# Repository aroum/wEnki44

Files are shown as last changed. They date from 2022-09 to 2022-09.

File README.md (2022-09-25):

# wEnki44

wEnki44 is a wireless version of Enki42 with a useless appendix.

Gerber files and STL models can be downloaded in [releases](https://github.com/aroum/wEnki44/releases).

## Typing

youtube video (click pic) by [@krikun98](https://github.com/krikun98)

Watch the video (https://youtu.be/zcw8uevsyJg)

## wEnki42

**Q:** Why is the pcb logo "wEnki42" even though the keyboard is called "wEnki44"?

**A:** This is a call to break off the useless appendix and use the [Watchman’s Layouts ](https://github.com/aroum/Watchman-layouts).

## Inspiration

* [nrfMicro](https://github.com/joric/nrfmicro)
* [Jian](https://github.com/KGOH/Jian-Info)
* [enki42](https://www.reddit.com/r/ErgoMechKeyboards/comments/qeq2qg/enki42_slim_ergo_keyboard/)
  
## Features

* 44/42 keys
* Kailh Choc V1 switches
* Choc spacing
* Direct pins 
* Wireless
* Full body Tenting case with magnets
* Power switch and reset button
* NFC tag

# Firmware

[wEnki44 zmk config](https://github.com/krikun98/zmk-config/tree/wEnki44) by [@krikun98](https://github.com/krikun98)

You can use firmware from [Jorian840](https://github.com/krikun98/jorian840), they are fully compatible. 

# BOM

| Item | Quantity | Remarks |
| --- | ---: | --- |
| [Kailh Choc V1](https://aliexpress.ru/item/32959996455.html) | 44/42 | switches |
| [Keycaps](https://aliexpress.ru/item/33026798318.html) | 44/42 | 1U (choc spacing) |
| [SMD button 3x4x2mm](https://aliexpress.ru/item/1005003812819985.html) | 2 | for reset |
| [MSK-12C02](https://aliexpress.ru/item/1005001398386692.html) | 2 | Power switch |
| [702035](https://aliexpress.ru/item/1005003738158239.html) | 2 | Or any battery size up to 21x47x8.8mm|
| [Magnets](https://aliexpress.ru/item/1005002757445161.html) | 50-70 | disc 7x2 mm |
| [Bumpers](https://aliexpress.ru/item/4001188580018.html) | 28 | 5x2 mm |
| [NFC-tag Ntag213](https://aliexpress.ru/item/1005001731694350.html) | 1-2 | for top case |

[Holyiot 18010](https://aliexpress.ru/item/32951888809.html) is used as a BLE module. 

All everything else is the same to [nrfMicro](https://github.com/joric/nrfmicro/wiki/Components)

Interactive BOM is located ```/pcb/ibom```

# NFC

You can program an NFC tag to connect to a keyboard or open a KLE using the [NFC Tools](https://play.google.com/store/apps/details?id=com.wakdev.wdnfc) app

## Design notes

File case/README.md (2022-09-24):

# CASE
 
For left-handed version you need to mirror the model.

The pcb is fixed by friction and screws. Use scale factor or sandpaper to fit details

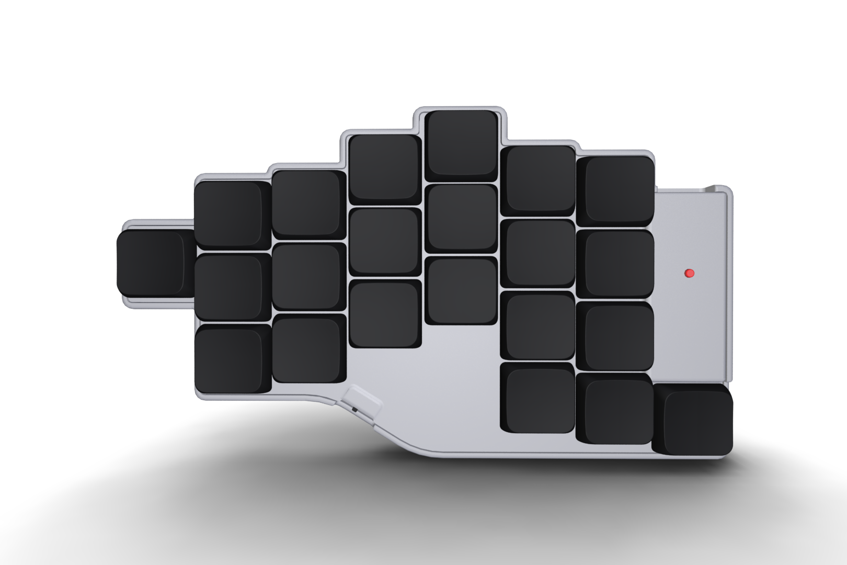
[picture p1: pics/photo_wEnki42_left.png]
wEnki42_left

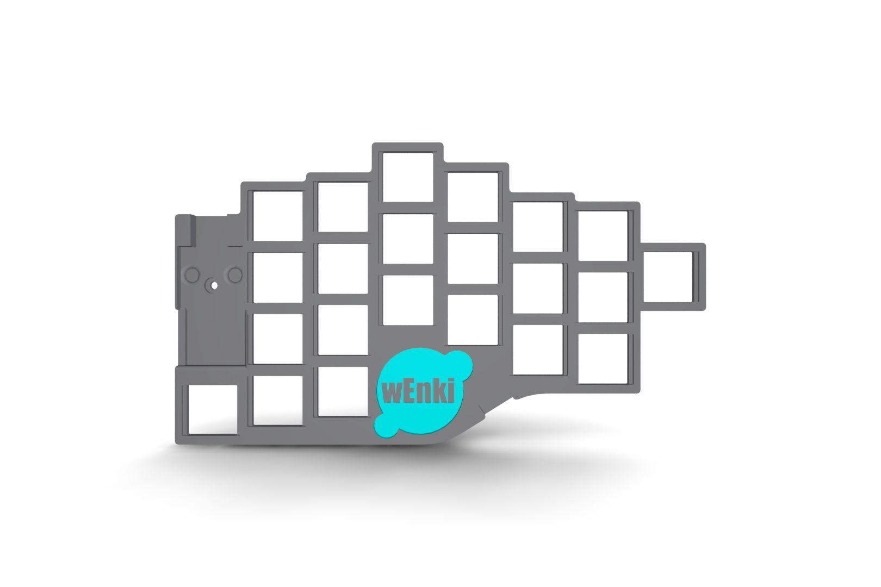
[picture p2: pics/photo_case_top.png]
case_top

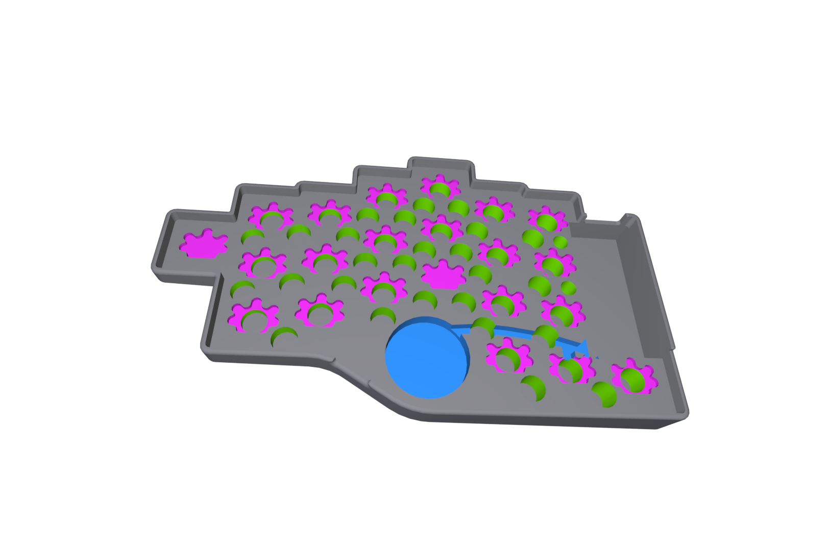
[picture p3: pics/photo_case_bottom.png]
case_bottom


# Print options: 
* Printer: Voxelab proxima
* Rafts: No
* Supports: Yes
* Resolution: 0.05mm
* Resin material: ABS-like

# STL
STL models for 44 & 42 variants can be downloaded in [releases](https://github.com/aroum/kalmar/releases).

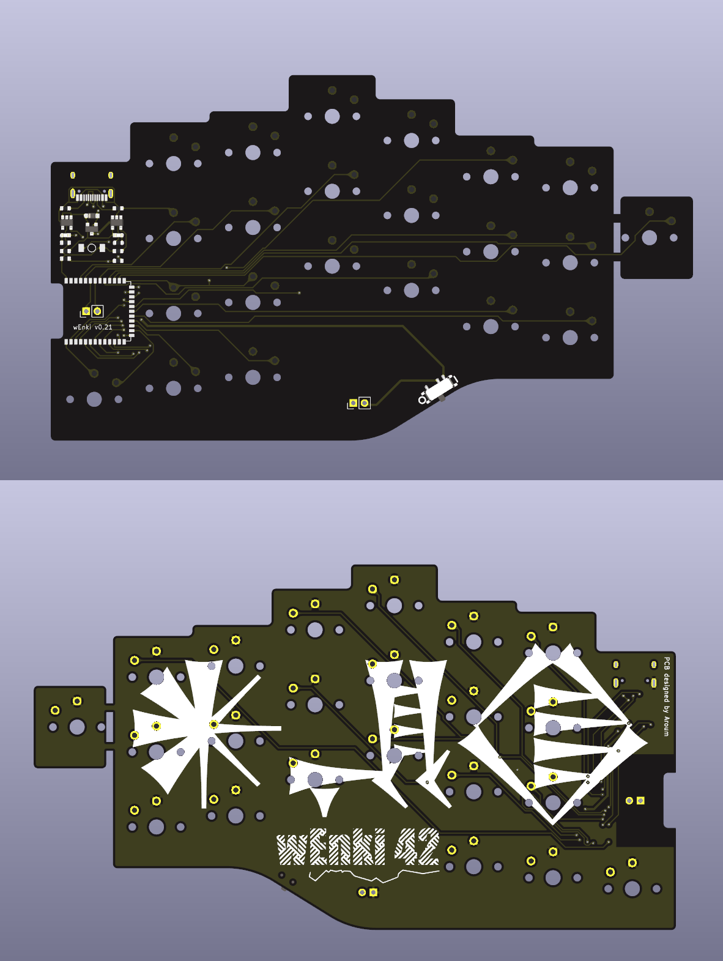
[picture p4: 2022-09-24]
pics/pcb.png

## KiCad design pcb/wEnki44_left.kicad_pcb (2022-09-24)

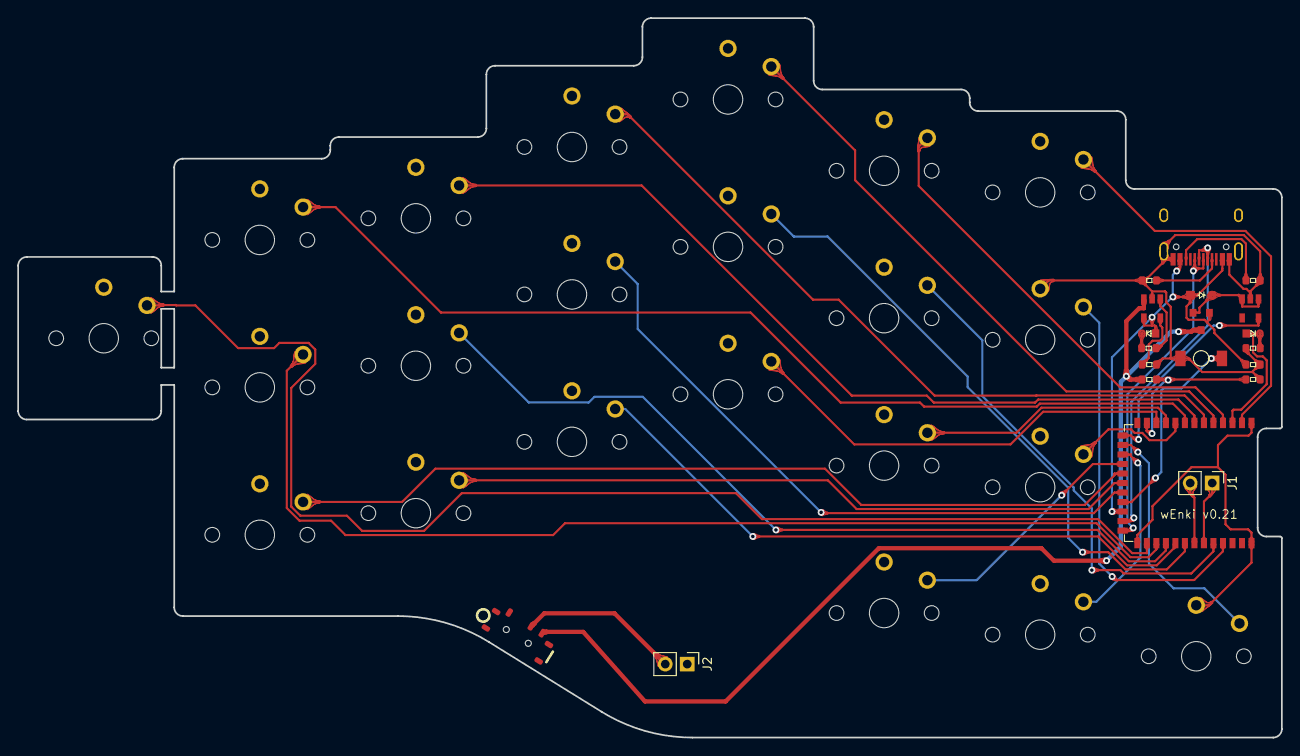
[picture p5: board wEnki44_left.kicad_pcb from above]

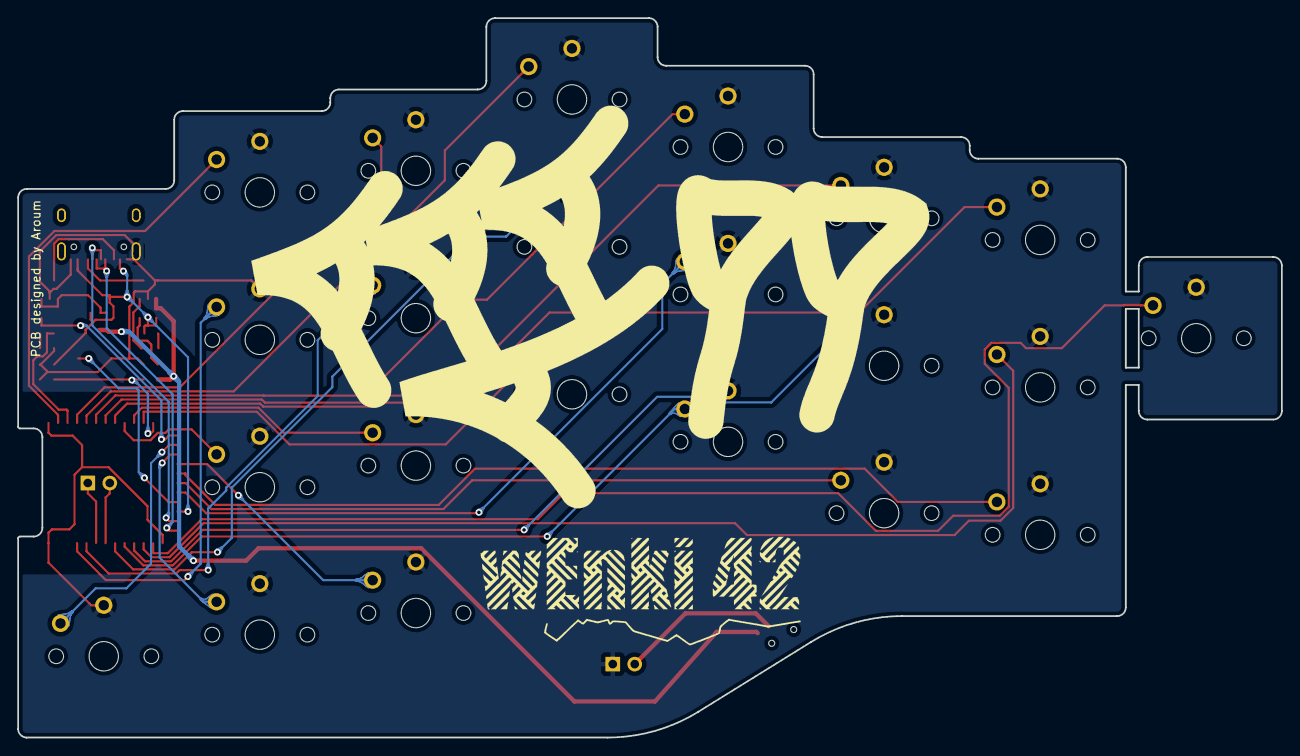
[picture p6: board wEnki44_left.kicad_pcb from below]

Board: 2 copper layers, 146.1 x 83.2 mm, 44 parts (2 on the bottom side), 41 nets.

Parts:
D22: RED; LED_0603_1608Metric
D23: BLUE; LED_0603_1608Metric
D24: 1N5819; D_SOD-323_HandSoldering
J1: SWD; PinHeader_1x02_P2.54mm_Vertical
J2: Ex_Bat; PinHeader_1x02_P2.54mm_Vertical
J3: USB-C Conn; USB_C_Receptacle_HRO_TYPE-C-31-M-12_round
Q1: AO3407; SOT-23
R1, R5: 1K; R_0603_1608Metric
R2: RPROG; R_0603_1608Metric
R3, R4: 5.1K; R_0603_1608Metric
R6: 100K; R_0603_1608Metric
R7: 820K; R_0603_1608Metric
R8: 2M; R_0603_1608Metric
RSW1: SW_PUSH; SW_3x4x2_2legs
SW1, SW2, SW3, SW4, SW5, SW6, SW7, SW8, SW9, SW10, SW11, SW12, SW13, SW14, SW15, SW16, SW17, SW18, SW19, SW20, SW21, SW23: SW_PUSH; ChocV1_1u
SW22: SW_SPDT; SW_MSK-12C02
U1: Holyiot-18010
U2: TP4054; SOT-23-5
U3: XC6220B331MR-G; SOT-23-5
logo1: Logo; Logo_wEnki42_mini
logoL1: Logo; Logo_42_big

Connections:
BATTERY_PIN: R7.2, R8.1, U1.12 (P0.04)
BLUE_LED: D23.2 (A), U1.3 (P1.10)
CC1: J3.A5 (CC1), R4.1
CC2: J3.B5 (CC2), R3.1
DATA+: J3.A6 (D+), J3.B6 (D+), U1.24 (D+)
DATA-: J3.A7 (D-), J3.B7 (D-), U1.23 (D-)
GND: J2.1, J3.A1 (GND), J3.A12 (GND), J3.B1 (GND), J3.B12 (GND), J3.S1 (SHIELD), R2.2, R3.2, R4.2, R5.2, R6.2, R8.2, RSW1.2, SW1.2, SW2.2, SW3.2, SW4.2, SW5.2, SW6.2, SW7.2, SW8.2, SW9.2, SW10.2, SW11.2, SW12.2, SW13.2, SW14.2, SW15.2, SW16.2, SW17.2, SW18.2, SW19.2, SW20.2, SW21.2, SW23.2, U1.1 (GND), U1.25 (GND), U1.37 (GND), U2.2 (VSS), U3.2 (GND)
unnamed: D22.1 (K), R1.1
unnamed: D23.1 (K), R5.1
unnamed: D24.1 (K), Q1.2 (S), U3.1 (VIN), U3.3 (EN)
unnamed: R1.2, U2.1 (STAT)
unnamed: R2.1, U2.5 (PROG)
R1C1: SW1.1, U1.8 (P0.28)
R1C2: SW2.1, U1.7 (P0.02)
R1C3: SW3.1, U1.6 (P0.03)
R1C4: SW4.1, U1.5 (P1.15)
R1C5: SW5.1, U1.4 (P1.13)
R1C6: SW6.1, U1.2 (P1.11)
R2C0: SW23.1, U1.26 (P0.22)
R2C1: SW7.1, U1.27 (P1.00)
R2C2: SW8.1, U1.28 (P1.03)
R2C3: SW9.1, U1.20 (P0.19)
R2C4: SW10.1, U1.30 (P1.02)
R2C5: SW11.1, U1.33 (P1.04)
R2C6: SW12.1, U1.34 (P1.06)
R3C1: SW13.1, U1.18 (P0.23)
R3C2: SW14.1, U1.19 (P0.21)
R3C3: SW15.1, U1.29 (P1.01)
R3C4: SW16.1, U1.11 (P0.31)
R3C5: SW17.1, U1.10 (P0.30)
R3C6: SW18.1, U1.9 (P0.29)
R4C5: SW19.1, U1.17 (P0.12)
R4C6: SW20.1, U1.16 (P1.09)
R4C7: SW21.1, U1.15 (P0.07)
SWC: J1.2, U1.31 (SWDCLK)
SWD: J1.1, U1.32 (SWDIO)
VBAT: J2.2, SW22.2 (B)
VBAT2: Q1.3 (D), R7.1, SW22.3 (C), U2.3 (VBAT)
VBUS: D22.2 (A), D24.2 (A), J3.A4 (VBUS), J3.A9 (VBUS), J3.B4 (VBUS), J3.B9 (VBUS), Q1.1 (G), R6.1, U1.22 (VBUS), U2.4 (VDD)
nRF_VDD: U1.14 (VDD_nRF), U3.5 (VOUT)
reset: RSW1.1, U1.21 (P0.18/RESET)
